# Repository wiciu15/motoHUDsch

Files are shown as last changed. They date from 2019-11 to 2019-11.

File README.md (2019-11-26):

# motoHUDsch
KiCad Schematic and PCB for STM32F103-based motorcycle digital instrument cluster with 2.8in ILI9341 LCD and X27.168 stepper motor for dial gauge indicator.

<b>Firmware - https://github.com/wiciu15/motoHUDini</b>

<b>Enclosure - https://github.com/wiciu15/motoHUDencl </b>

<b>Demo video - https://youtu.be/awKXkiaZZUE</b>

3d back

3d front

final render

Rev1 has problems with thermals on 5V regulator, ADC accuracy and other brain farts like bad footprint or silkscreen marking

Rev2 comes with fixes and some new features like button switches. It is not perfect however :/

<b>Rev2 need some mods to work properly:</b>

<b>-U2 needs to be powered from a 5V rail or changed to a rail-to-rail dual opAmp in same package (LM2903 is not rail-to-rail unfortunately)</b>

<b>-C25 and C21 need a parallel resistor to discharge them (100k-200k ohm range)</b>

<b>-startup current is too high and destroys fuses immidately - I switched F1 fuse with a 1206 2,2ohm resistor </b>

If you don't have/like KiCAD there are schematic PDFs and gerber files.

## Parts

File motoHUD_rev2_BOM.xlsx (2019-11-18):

Item | Qty | Reference(s) | Value | LibPart | Footprint | Link | Cena/szt | Cena
1 | 1 | C11 | 2,2u | Device:C_Small | Capacitor_SMD:C_0805_2012Metric_Pad1.15x1.40mm_HandSolder | ~
2 | 4 | C12, C14, C15, C17 | 10u 16v | Device:C_Small | Capacitor_SMD:C_0805_2012Metric_Pad1.15x1.40mm_HandSolder | ~
3 | 4 | C13, C23, C24, C34 | 0,1u | Device:C_Small | Capacitor_SMD:C_0805_2012Metric_Pad1.15x1.40mm_HandSolder | ~
4 | 1 | C16 | 100u | Device:CP | Capacitor_THT:CP_Radial_D8.0mm_P3.50mm | ~
5 | 4 | C18, C21, C22, C25 | 22u | Device:C_Small | Capacitor_SMD:C_0805_2012Metric_Pad1.15x1.40mm_HandSolder | ~
6 | 4 | C30, C31, C32, C33 | 20p | Device:C_Small | Capacitor_SMD:C_0805_2012Metric_Pad1.15x1.40mm_HandSolder | ~
7 | 4 | D1, D2, D3, D5 | 1N4148W-7-F | Diode:1N4148 | Diode_SMD:D_SOD-123 | https://www.tme.eu/pl/details/1n4148w-7-f/diody-uniwersalne-smd/diodes-incorporated/
8 | 1 | D4 | STPS1L40A | Diode | Diode_SMD:D_SMA_Handsoldering | https://www.tme.eu/pl/details/stps1l40a/diody-schottky-smd/stmicroelectronics/
9 | 4 | D6, D7, D8, D9 | BCKLED | Device:LED | LED_SMD:LED_1206_3216Metric | https://www.tme.eu/pl/details/fyls-1206uwc/diody-led-smd-biale/foryard/
10 | 1 | D10 | LEDSTATUS | Device:LED | LED_SMD:LED_1206_3216Metric_Pad1.42x1.75mm_HandSolder | https://www.tme.eu/pl/details/osr51206c1e/diody-led-smd-kolorowe/optosupply/
11 | 1 | F1 | ESKA FUSE 0805-FF PW 0A5 | Device:Fuse_Small | Capacitor_SMD:C_1206_3216Metric_Pad1.42x1.75mm_HandSolder | https://www.tme.eu/pl/details/bsmd0805-ss0.5/bezpieczniki-smd-0805-superszybkie/eska/fuse-0805-ff-pw-0a5/
12 | 1 | J1 | POWER | Connector:Conn_01x03_Female | Connector_JST:JST_XH_B03B-XH-A_1x03_P2.50mm_Vertical | https://www.tme.eu/pl/details/mx-5267-03a/zlacza-sygnalowe-raster-2-50mm/molex/22-03-5035/
13 | 1 | J2 | THERM1 | Connector:Conn_01x02_Female | Connector_JST:JST_XH_B02B-XH-A_1x02_P2.50mm_Vertical | https://www.tme.eu/pl/details/mx-5267-02a/zlacza-sygnalowe-raster-2-50mm/molex/22-03-5025/
14 | 1 | J3 | THERM2 | Connector:Conn_01x02_Female | Connector_JST:JST_XH_B02B-XH-A_1x02_P2.50mm_Vertical | https://www.tme.eu/pl/details/mx-5267-02a/zlacza-sygnalowe-raster-2-50mm/molex/22-03-5025/
15 | 1 | J4 | HALL | Connector:Conn_01x03_Female | Connector_JST:JST_XH_B03B-XH-A_1x03_P2.50mm_Vertical | https://www.tme.eu/pl/details/mx-5267-03a/zlacza-sygnalowe-raster-2-50mm/molex/22-03-5035/
16 | 1 | J5 | SIG_RPM | Connector:Conn_01x02_Female | Connector_JST:JST_XH_B02B-XH-A_1x02_P2.50mm_Vertical | https://www.tme.eu/pl/details/mx-5267-02a/zlacza-sygnalowe-raster-2-50mm/molex/22-03-5025/
17 | 1 | J6 | SIGNAL | Connector:Conn_01x03_Female | Connector_JST:JST_XH_B03B-XH-A_1x03_P2.50mm_Vertical | https://www.tme.eu/pl/details/mx-5267-03a/zlacza-sygnalowe-raster-2-50mm/molex/22-03-5035/
18 | 1 | J7 | USB_B_Mini | Connector:USB_B_Mini | Connector_USB:USB_Mini-B_Lumberg_2486_01_Horizontal | https://www.tme.eu/pl/details/musb-b5-s-ra-smt/zlacza-usb-i-ieee1394/adam-tech/musb-b5-s-ra-tsmt-cs1/
19 | 1 | J8 | ICSP | Connector:Conn_01x03_Male | Connector_PinHeader_2.54mm:PinHeader_1x03_P2.54mm_Vertical | goldpin
20 | 1 | J9 | LCD Connector | Connector:Conn_01x18_Female | motoHUD:ILI9341 FFC | https://pl.aliexpress.com/item/32861524235.html?spm=a2g0s.9042311.0.0.60ae5c0fPdHgZW
21 | 1 | L1 | DLG-0403-220 | Device:L | Inductor_SMD:L_2816_7142Metric_Pad3.20x4.45mm_HandSolder | https://www.tme.eu/pl/details/dlg-0403-220/dlawiki-smd-mocy/ferrocore/
22 | 1 | M1 | X27 168 | Motor:Stepper_Motor_bipolar | motoHUD:X27-168 | http://www.infineon.com/dgdl/Application-Note-TLE8110EE_driving_UniPolarStepperMotor_V1.1.pdf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
23 | 2 | Q1, Q2 | 2N7002KQ-13 | Device:Q_NMOS_DGS | motoHUD:SOT-23 | https://www.tme.eu/pl/details/2n7002kq-13/tranzystory-z-kanalem-n-smd/diodes-incorporated/
24 | 6 | R11, R27, R28, R31, R54, R61 | 100k | Device:R | Resistor_SMD:R_0805_2012Metric_Pad1.15x1.40mm_HandSolder | ~
25 | 1 | R12 | 22k | Device:R | Resistor_SMD:R_0805_2012Metric_Pad1.15x1.40mm_HandSolder | ~
26 | 1 | R13 | 51,1k | Device:R | Resistor_SMD:R_0805_2012Metric_Pad1.15x1.40mm_HandSolder | ~
27 | 3 | R14, R73, R74 | 1,5k | Device:R | Resistor_SMD:R_0805_2012Metric_Pad1.15x1.40mm_HandSolder | ~
28 | 10 | R15, R21, R29, R41, R43, R45, R51, R52, R55, R211 | 10k | Device:R | Resistor_SMD:R_0805_2012Metric_Pad1.15x1.40mm_HandSolder | ~
29 | 4 | R16, R17, R32, R62 | 0R | Device:R | Resistor_SMD:R_0805_2012Metric_Pad1.15x1.40mm_HandSolder | ~
30 | 2 | R22, R23 | 7,6k | Device:R | Resistor_SMD:R_0805_2012Metric_Pad1.15x1.40mm_HandSolder | ~
31 | 2 | R24, R25 | 5,1k | Device:R | Resistor_SMD:R_0805_2012Metric_Pad1.15x1.40mm_HandSolder | ~
32 | 1 | R26 | 2,2k | Device:R | Resistor_SMD:R_0805_2012Metric_Pad1.15x1.40mm_HandSolder | ~
33 | 4 | R33, R34, R35, R36 | 100R | Device:R | Resistor_SMD:R_0805_2012Metric_Pad1.15x1.40mm_HandSolder | ~
34 | 3 | R42, R44, R46 | 3k3 | Device:R | Resistor_SMD:R_0805_2012Metric_Pad1.15x1.40mm_HandSolder | ~
35 | 2 | R53, R210 | 1M | Device:R | Resistor_SMD:R_0805_2012Metric_Pad1.15x1.40mm_HandSolder | ~
36 | 4 | R63, R64, R65, R66 | 39R | Device:R | Resistor_SMD:R_0805_2012Metric_Pad1.15x1.40mm_HandSolder | ~
37 | 2 | R71, R72 | 22R | Device:R | Resistor_SMD:R_0805_2012Metric_Pad1.15x1.40mm_HandSolder | ~
38 | 1 | SW1 | TACTM-613N-F | Switch:SW_Push | Button_Switch_SMD:SW_SPST_EVQQ2 | https://www.tme.eu/pl/details/tactm-613n-f/mikroprzelaczniki-tact/ninigi/
39 | 1 | U1 | STM32F103C8Tx | MCU_ST_STM32F1:STM32F103C8Tx | Package_QFP:LQFP-48_7x7mm_P0.5mm | https://www.tme.eu/pl/details/stm32f103c8t6/mikrokontrolery-st/stmicroelectronics/
40 | 2 | U2, U3 | LM2904DT | Amplifier_Operational:LM2904 | Package_SO:SO-8_5.3x6.2mm_P1.27mm | https://www.tme.eu/pl/details/lm2904dt/wzmacniacze-operacyjne-smd/stmicroelectronics/
41 | 1 | U4 | AZ1117-3.3 | Regulator_Linear:AZ1117-3.3 | Package_TO_SOT_SMD:SOT-223 | https://www.tme.eu/pl/details/az1117ch-3.3trg1/stabilizatory-napiecia-nieregulowane-ldo/diodes-incorporated/
42 | 1 | U5 | MCP16301 | Regulator_Switching:MCP16301 | Package_TO_SOT_SMD:SOT-23-6 | https://www.tme.eu/pl/details/mcp16301t-i_chy/regulatory-napiecia-uklady-dc-dc/microchip-technology/
43 | 1 | U6 | M95320-WMN6P | Memory_EEPROM:M95256-WMN6P | Package_SO:SOIC-8_3.9x4.9mm_P1.27mm | https://www.tme.eu/pl/details/m95320-wmn6tp/pamieci-eeprom-szeregowe/stmicroelectronics/
44 | 1 | Y1 | HC49USM-FF3F18-8M | Device:Crystal | Crystal:Crystal_SMD_HC49-SD_HandSoldering | https://www.tme.eu/pl/details/hc49usm-ff3f8.00/rezonatory-kwarcowe-smd/ilsi/hc49usm-ff3f18-8-0000/
45 | 1 | Y2 | LFXTAL009678 | Device:Crystal | Crystal:Crystal_SMD_3215-2Pin_3.2x1.5mm | https://www.tme.eu/pl/details/32.768k-cfpx217/rezonatory-kwarcowe-smd/iqd-frequency-products/lfxtal009678/

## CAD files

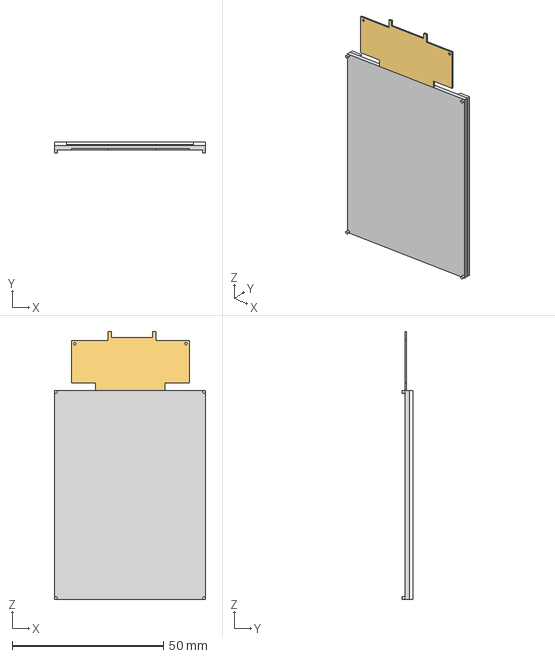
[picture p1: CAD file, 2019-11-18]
28inLCDILI9341.step
50.0 x 3.60 x 88.7 mm

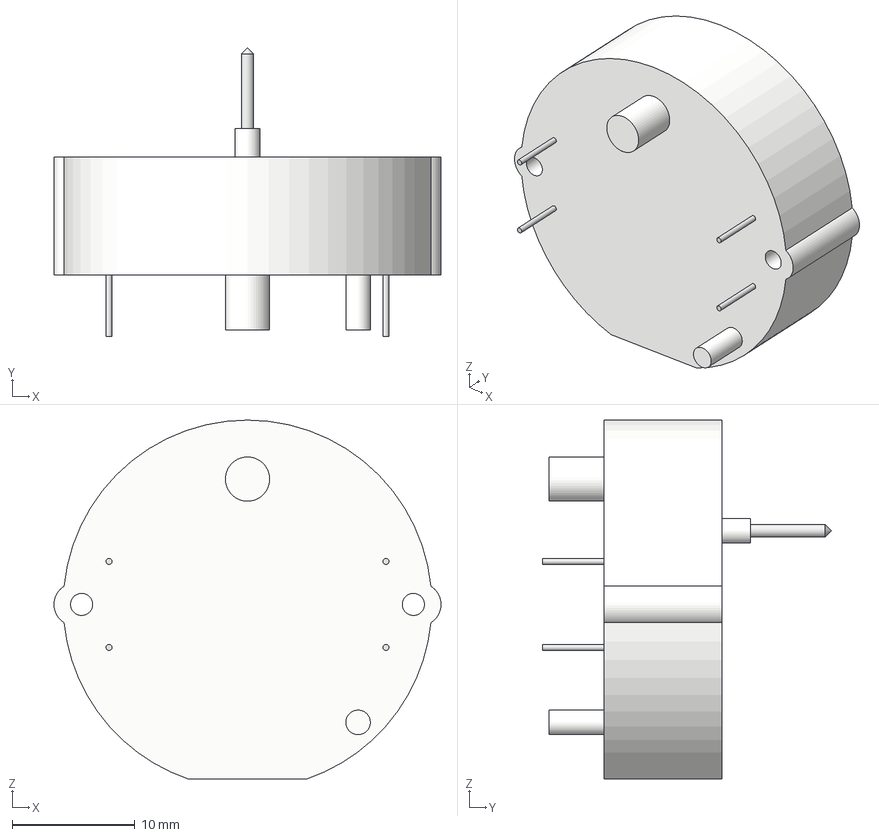
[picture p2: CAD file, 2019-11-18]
x27168.step
31.5 x 23.5 x 29.2 mm

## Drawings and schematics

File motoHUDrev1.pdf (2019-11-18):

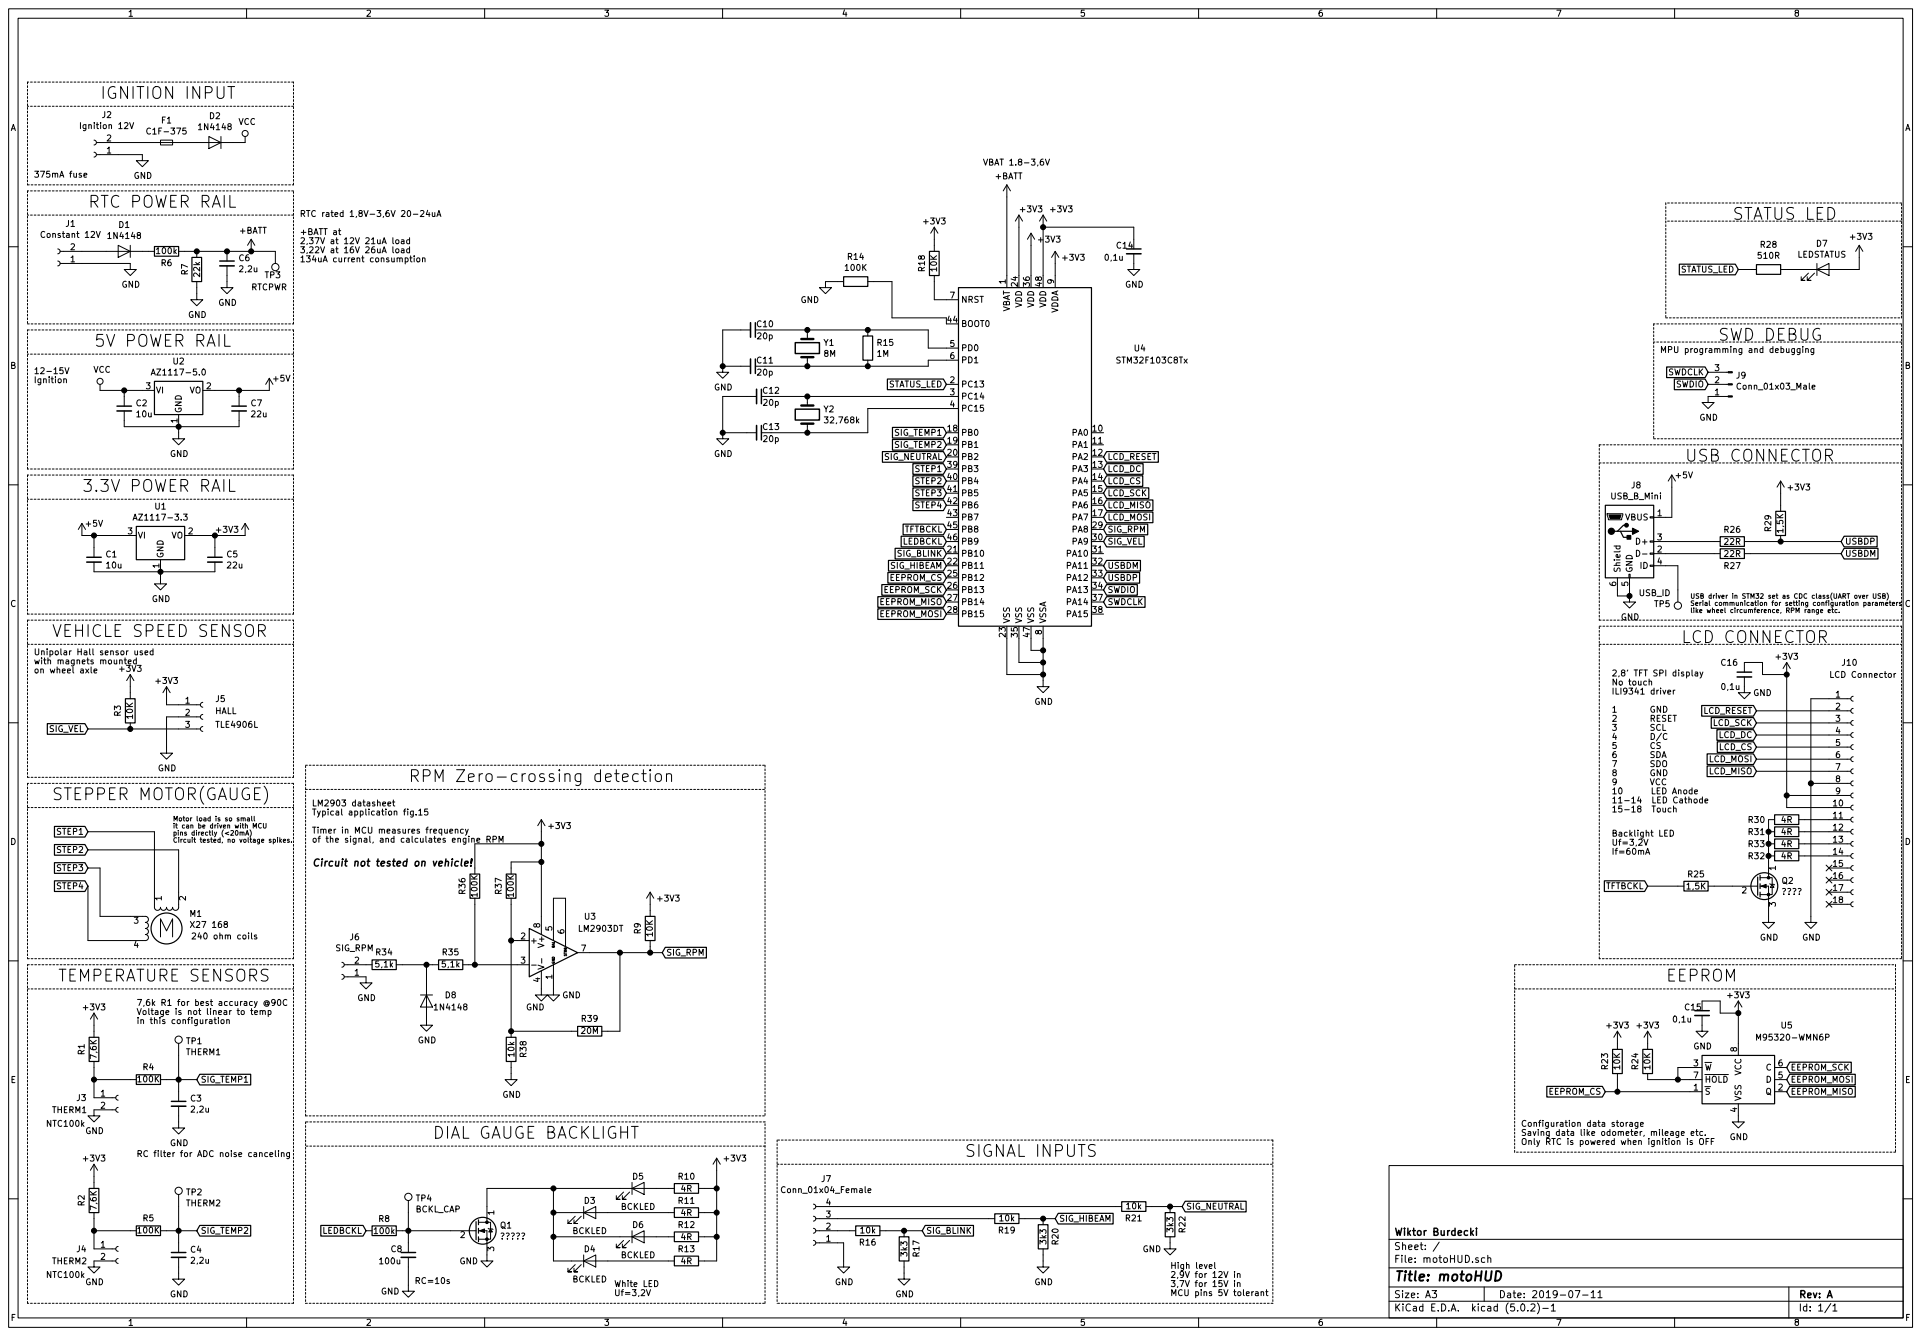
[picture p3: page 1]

375mA fuse Unipolar Hall sensor used
1N4148 RTC POWER RAIL

RTC rated 1,8V-3,6V 20-24uA
+BATT at 2,37V at 12V 21uA load

STATUS LED

1 VDD 24 VDD 36 VDD 48 VDDA

9 VSS 23 VSS 35 VSS 47 VSSA

like wheel circumference, RPM range etc. MPU programming and debugging

USB driver in STM32 set as CDC class(UART over USB) Serial communication for setting configuration parameters

VEHICLE SPEED SENSOR

LCD CONNECTOR

LCD_MOSI 2,8' TFT SPI display No touch

240 ohm coils STEPPER MOTOR(GAUGE)

LM2903 datasheet Typical application fig.15

it can be driven with MCU

Timer in MCU measures frequency
of the signal, and calculates engine RPM

TEMPERATURE SENSORS

Voltage is not linear to temp
in this configuration

Configuration data storage Saving data like odometer, mileage etc. Only RTC is powered when ignition is OFF

RC filter for ADC noise canceling

SIG_NEUTRAL High level 2,9V for 12V in

File: motoHUD.sch Sheet: / Wiktor Burdecki

3,7V for 15V in MCU pins 5V tolerant

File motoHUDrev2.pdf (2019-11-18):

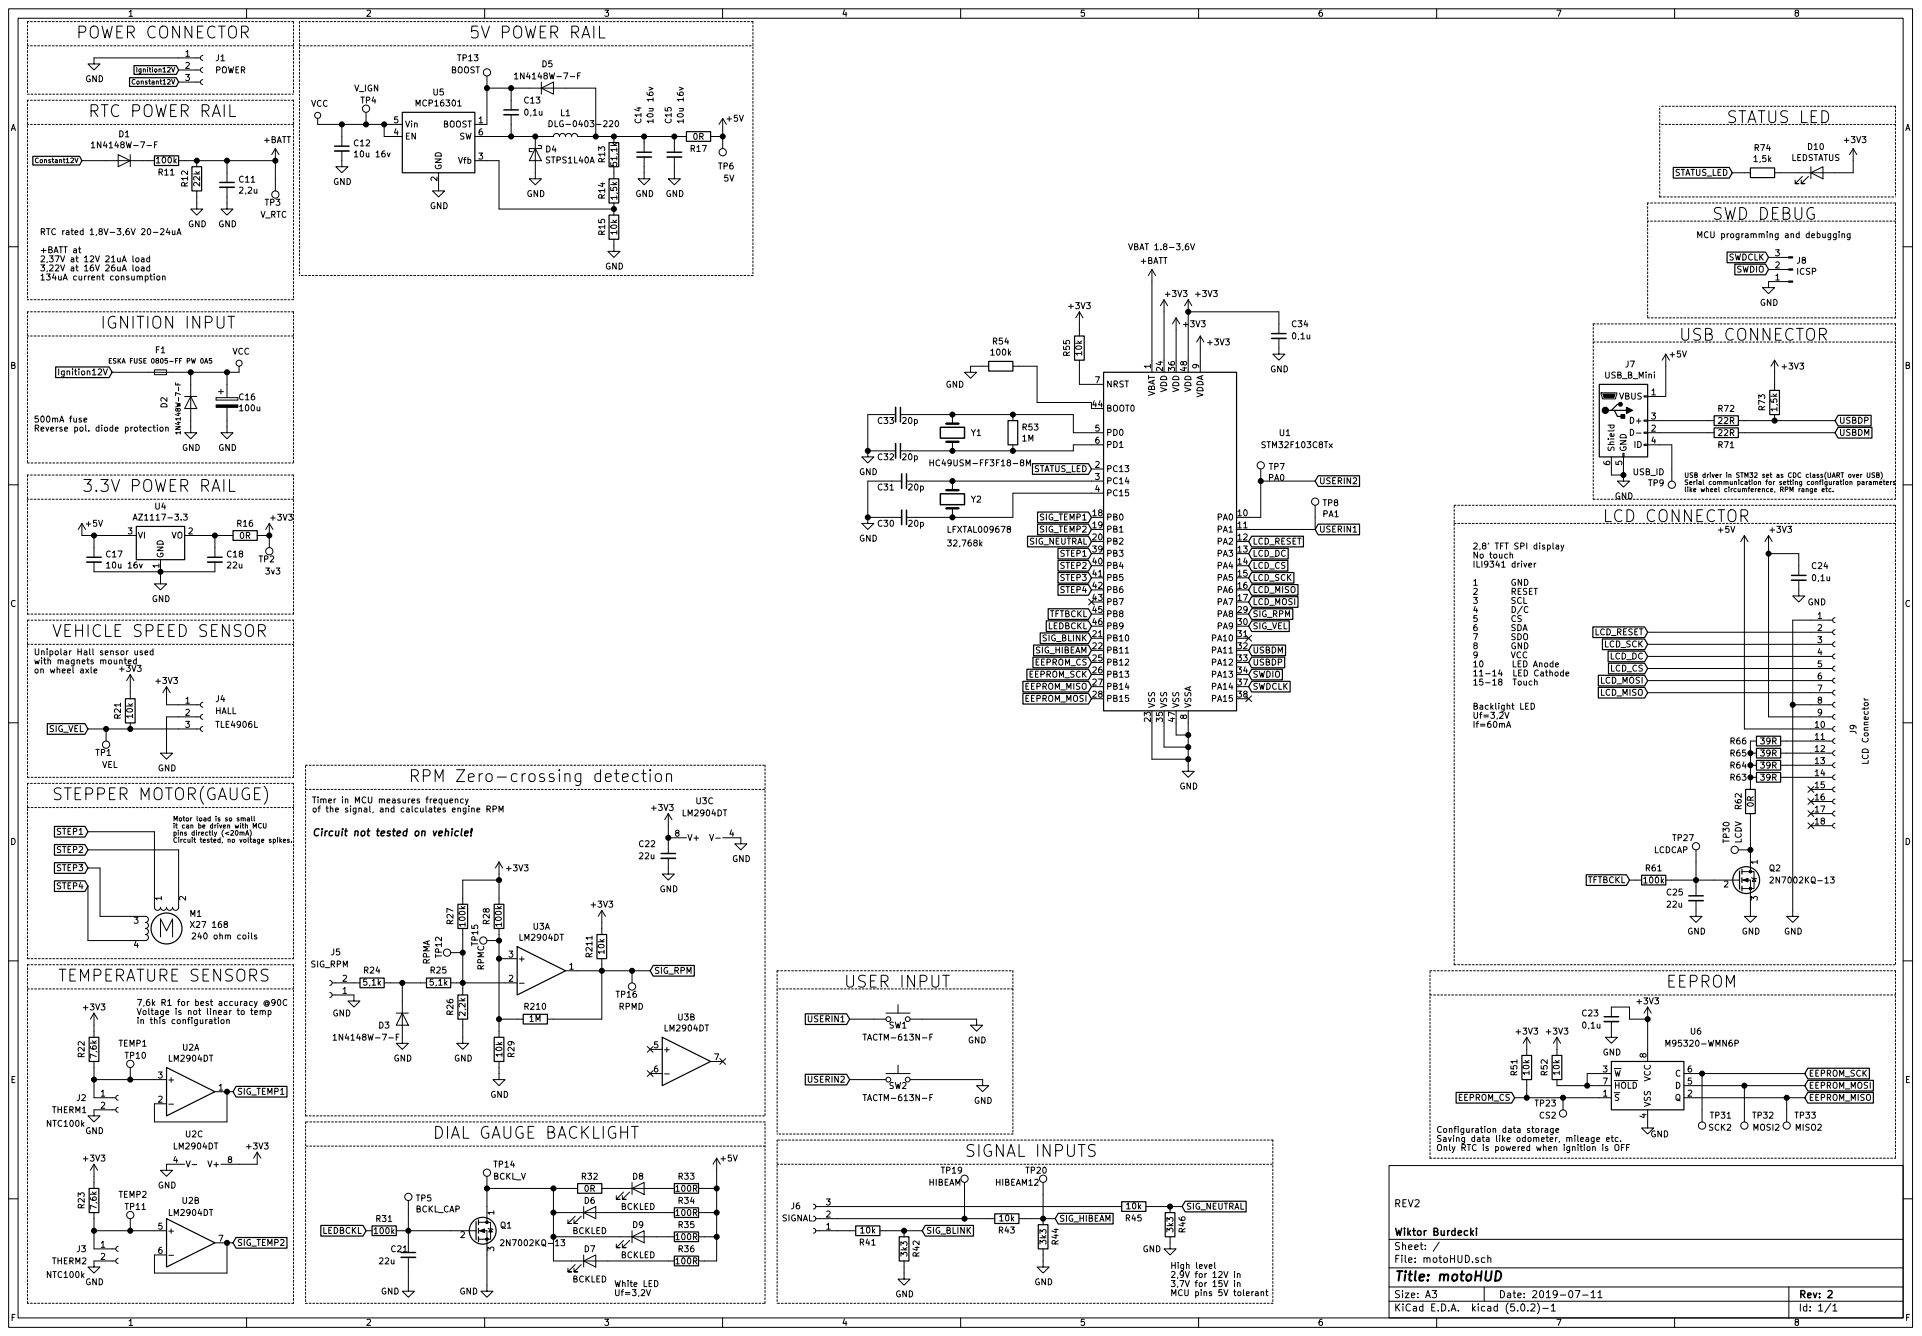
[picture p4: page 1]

2 Vfb 3 EN 4 Vin 5 SW 6 U5 MCP16301 GND

RTC rated 1,8V-3,6V 20-24uA
+BATT at 2,37V at 12V 21uA load
3,22V at 16V 26uA load

like wheel circumference, RPM range etc. MCU programming and debugging

ESKA FUSE 0805-FF PW 0A5

1 VDD 24 VDD 36 VDD 48 VDDA

9 VSS 23 VSS 35 VSS 47 VSSA

500mA fuse Reverse pol. diode protection

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

LCD_MOSI 2,8' TFT SPI display No touch

VEHICLE SPEED SENSOR | 3v3 TP1VEL

Unipolar Hall sensor used with magnets mounted

240 ohm coils STEPPER MOTOR(GAUGE)

Timer in MCU measures frequency

it can be driven with MCU

7,6k R1 for best accuracy @90C
Voltage is not linear to temp

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

SIG_NEUTRAL High level 2,9V for 12V in

File: motoHUD.sch Sheet: / Wiktor Burdecki REV2

3,7V for 15V in MCU pins 5V tolerant

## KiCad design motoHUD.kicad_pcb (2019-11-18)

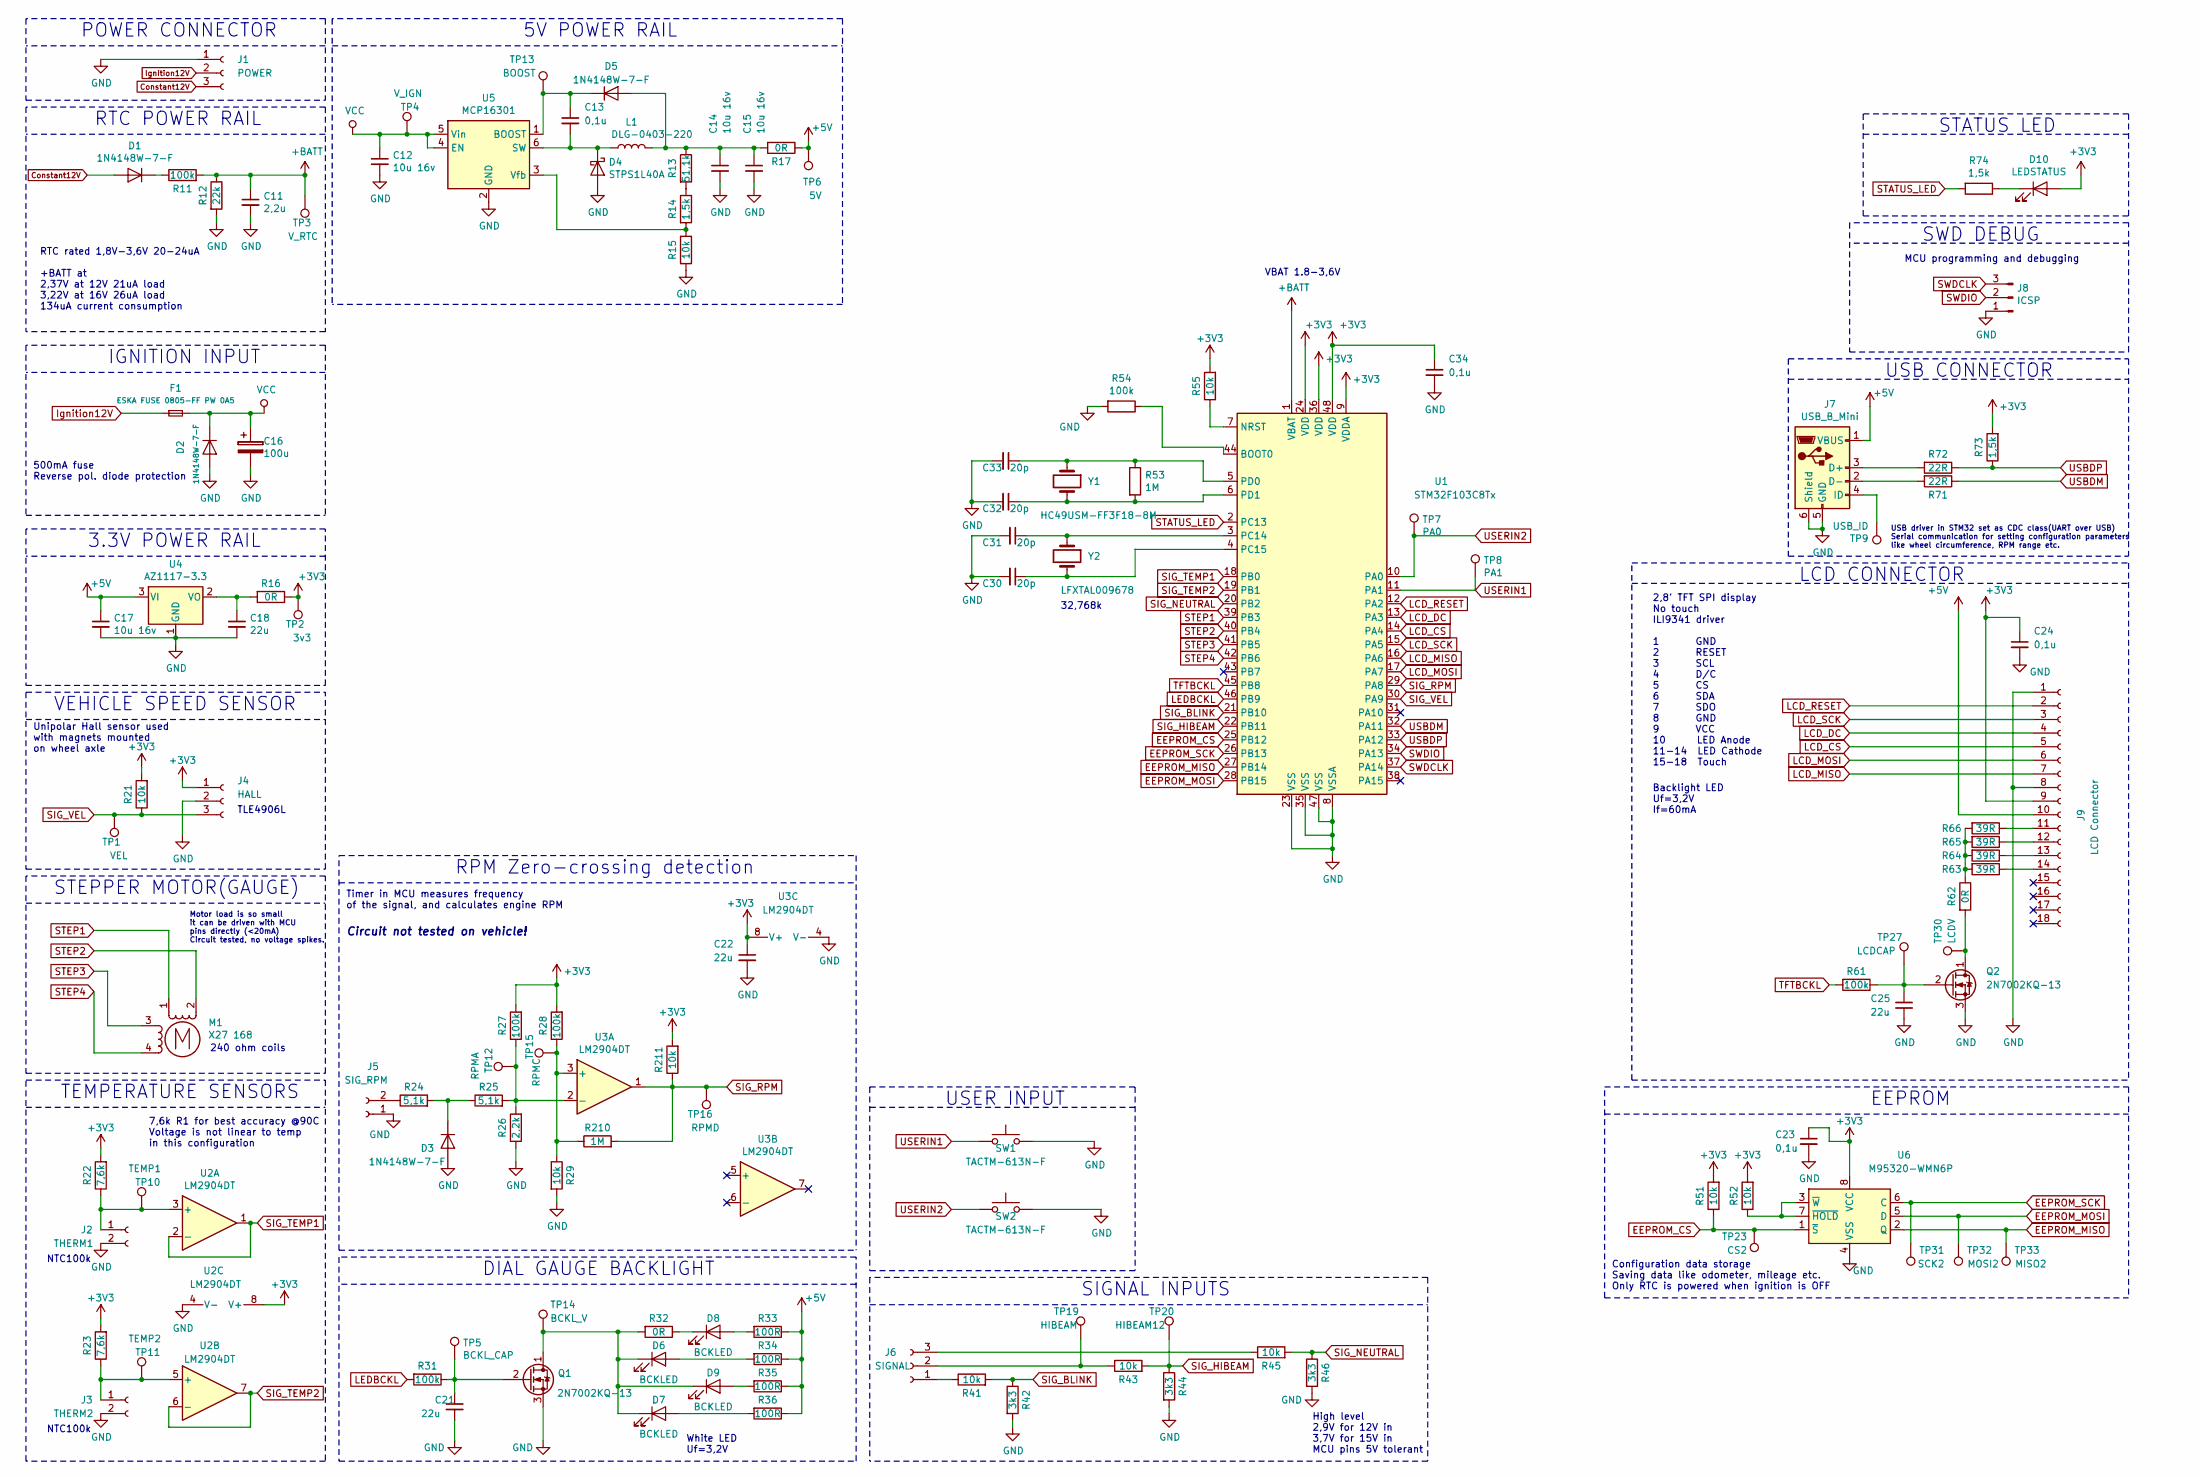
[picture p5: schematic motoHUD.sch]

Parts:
C11: 2,2u; C_0805_2012Metric_Pad1.15x1.40mm_HandSolder
C12, C14, C15, C17: 10u 16v; C_0805_2012Metric_Pad1.15x1.40mm_HandSolder
C13, C23, C24, C34: 0,1u; C_0805_2012Metric_Pad1.15x1.40mm_HandSolder
C16: 100u; CP_Radial_D8.0mm_P3.50mm
C18, C21, C22, C25: 22u; C_0805_2012Metric_Pad1.15x1.40mm_HandSolder
C30, C31, C32, C33: 20p; C_0805_2012Metric_Pad1.15x1.40mm_HandSolder
D1, D2, D3, D5: 1N4148W-7-F; D_SOD-123
D4: STPS1L40A; D_SMA_Handsoldering
D6, D7, D8, D9: BCKLED; LED_1206_3216Metric
D10: LEDSTATUS; LED_1206_3216Metric_Pad1.42x1.75mm_HandSolder
F1: ESKA FUSE 0805-FF PW 0A5; C_1206_3216Metric_Pad1.42x1.75mm_HandSolder
J1: POWER; JST_XH_B03B-XH-A_1x03_P2.50mm_Vertical
J2: THERM1; JST_XH_B02B-XH-A_1x02_P2.50mm_Vertical
J3: THERM2; JST_XH_B02B-XH-A_1x02_P2.50mm_Vertical
J4: HALL; JST_XH_B03B-XH-A_1x03_P2.50mm_Vertical
J5: SIG_RPM; JST_XH_B02B-XH-A_1x02_P2.50mm_Vertical
J6: SIGNAL; JST_XH_B03B-XH-A_1x03_P2.50mm_Vertical
J7: USB_B_Mini; USB_Mini-B_Lumberg_2486_01_Horizontal
J8: ICSP; PinHeader_1x03_P2.54mm_Vertical
J9: LCD Connector; ILI9341FFC
L1: DLG-0403-220
M1: X27 168; X27-168
Q1, Q2: 2N7002KQ-13; SOT-23
R11, R27, R28, R31, R54, R61: 100k; R_0805_2012Metric_Pad1.15x1.40mm_HandSolder
R12: 22k; R_0805_2012Metric_Pad1.15x1.40mm_HandSolder
R13: 51,1k; R_0805_2012Metric_Pad1.15x1.40mm_HandSolder
R14, R73, R74: 1,5k; R_0805_2012Metric_Pad1.15x1.40mm_HandSolder
R15, R21, R29, R41, R43, R45, R51, R52, R55, R211: 10k; R_0805_2012Metric_Pad1.15x1.40mm_HandSolder
R16, R17, R32, R62: 0R; R_0805_2012Metric_Pad1.15x1.40mm_HandSolder
R22, R23: 7,6k; R_0805_2012Metric_Pad1.15x1.40mm_HandSolder
R24, R25: 5,1k; R_0805_2012Metric_Pad1.15x1.40mm_HandSolder
R26: 2,2k; R_0805_2012Metric_Pad1.15x1.40mm_HandSolder
R33, R34, R35, R36: 100R; R_0805_2012Metric_Pad1.15x1.40mm_HandSolder
R42, R44, R46: 3k3; R_0805_2012Metric_Pad1.15x1.40mm_HandSolder
R53, R210: 1M; R_0805_2012Metric_Pad1.15x1.40mm_HandSolder
R63, R64, R65, R66: 39R; R_0805_2012Metric_Pad1.15x1.40mm_HandSolder
R71, R72: 22R; R_0805_2012Metric_Pad1.15x1.40mm_HandSolder
SW1, SW2: TACTM-613N-F
TP1: VEL; TestPoint_THTPad_D2.0mm_Drill1.0mm
TP2: 3v3; TestPoint_THTPad_D2.0mm_Drill1.0mm
TP3: V_RTC; TestPoint_THTPad_D2.0mm_Drill1.0mm
TP4: V_IGN; TestPoint_THTPad_D2.0mm_Drill1.0mm
TP5: BCKL_CAP; TestPoint_THTPad_D2.0mm_Drill1.0mm
TP6: 5V; TestPoint_THTPad_D2.0mm_Drill1.0mm
TP7: PA0; TestPoint_THTPad_D2.0mm_Drill1.0mm
TP8: PA1; TestPoint_THTPad_D2.0mm_Drill1.0mm
TP9: USB_ID; TestPoint_THTPad_D2.0mm_Drill1.0mm
TP10: TEMP1; TestPoint_THTPad_D2.0mm_Drill1.0mm
TP11: TEMP2; TestPoint_THTPad_D2.0mm_Drill1.0mm
TP12: RPMA; TestPoint_THTPad_D2.0mm_Drill1.0mm
TP13: BOOST; TestPoint_THTPad_D2.0mm_Drill1.0mm
TP14: BCKL_V; TestPoint_THTPad_D2.0mm_Drill1.0mm
TP15: RPMC; TestPoint_THTPad_D2.0mm_Drill1.0mm
TP16: RPMD; TestPoint_THTPad_D2.0mm_Drill1.0mm
TP19: HIBEAM; TestPoint_THTPad_D2.0mm_Drill1.0mm
TP20: HIBEAM12; TestPoint_THTPad_D2.0mm_Drill1.0mm
TP23: CS2; TestPoint_THTPad_D2.0mm_Drill1.0mm
TP27: LCDCAP; TestPoint_THTPad_D2.0mm_Drill1.0mm
TP30: LCDV; TestPoint_THTPad_D2.0mm_Drill1.0mm
TP31: SCK2; TestPoint_THTPad_D2.0mm_Drill1.0mm
TP32: MOSI2; TestPoint_THTPad_D2.0mm_Drill1.0mm
TP33: MISO2; TestPoint_THTPad_D2.0mm_Drill1.0mm
U1: STM32F103C8Tx; LQFP-48_7x7mm_P0.5mm
U2, U3: LM2904DT; SO-8_5.3x6.2mm_P1.27mm
U4: AZ1117-3.3; SOT-223
U5: MCP16301; SOT-23-6
U6: M95320-WMN6P; SOIC-8_3.9x4.9mm_P1.27mm
Y1: HC49USM-FF3F18-8M; Crystal_SMD_HC49-SD_HandSoldering
Y2: LFXTAL009678; Crystal_SMD_3215-2Pin_3.2x1.5mm

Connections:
+3V3: C22.1, C23.1, C24.1, C34.1, D10.2 (A), J4.1, J9.9, R16.1, R21.2, R22.2, R23.2, R27.2, R28.2, R51.2, R52.2, R55.2, R73.2, R211.2, TP2.1, U1.9 (VDDA), U1.24 (VDD), U1.36 (VDD), U1.48 (VDD), U2.8 (V+), U3.8 (V+), U6.8 (VCC)
+5V: C17.1, J7.1 (VBUS), J9.10, R17.1, R33.1, R34.1, R35.1, R36.1, TP6.1, U4.3 (VI)
+BATT: C11.1, R11.2, R12.1, TP3.1, U1.1 (VBAT)
Constant12V: D1.2 (A), J1.3
EEPROM_CS: R51.1, TP23.1, U1.25 (PB12), U6.1 (~S)
EEPROM_MISO: TP33.1, U1.27 (PB14), U6.2 (Q)
EEPROM_MOSI: TP32.1, U1.28 (PB15), U6.5 (D)
EEPROM_SCK: TP31.1, U1.26 (PB13), U6.6 (C)
GND: C11.2, C12.2, C14.2, C15.2, C16.2, C17.2, C18.2, C21.2, C22.2, C23.2, C24.2, C25.2, C30.2, C31.2, C32.2, C33.2, C34.2, D2.2 (A), D3.2 (A), D4.2 (A), J1.1, J2.2, J3.2, J4.2, J5.1, J7.5 (GND), J7.6 (Shield), J8.1, J9.1, J9.8, Q1.3 (S), Q2.3 (S), R12.2, R15.2, R26.1, R29.2, R42.2, R44.2, R46.2, R54.2, SW1.2, SW2.2, U1.8 (VSSA), U1.23 (VSS), U1.35 (VSS), U1.47 (VSS), U2.4 (V-), U3.4 (V-), U4.1 (GND), U5.2 (GND), U6.4 (VSS)
Ignition12V: F1.1, J1.2
LCD_CS: J9.5, U1.14 (PA4)
LCD_DC: J9.4, U1.13 (PA3)
LCD_MISO: J9.7, U1.16 (PA6)
LCD_MOSI: J9.6, U1.17 (PA7)
LCD_RESET: J9.2, U1.12 (PA2)
LCD_SCK: J9.3, U1.15 (PA5)
LEDBCKL: R31.2, U1.46 (PB9)
unnamed: C13.1, D5.1 (K), TP13.1, U5.1 (BOOST)
unnamed: C13.2, D4.1 (K), L1.1, U5.6 (SW)
unnamed: C14.1, C15.1, D5.2 (A), L1.2, R13.1, R17.2
unnamed: C18.1, R16.2, U4.2 (VO)
unnamed: C21.1, Q1.2 (G), R31.1, TP5.1
unnamed: C25.1, Q2.2 (G), R61.1, TP27.1
unnamed: C30.1, U1.4 (PC15), Y2.2
unnamed: C31.1, U1.3 (PC14), Y2.1
unnamed: C32.1, R53.2, U1.6 (PD1), Y1.2
unnamed: C33.1, R53.1, U1.5 (PD0), Y1.1
unnamed: D1.1 (K), R11.1
unnamed: D3.1 (K), R24.2, R25.1
unnamed: D6.1 (K), D7.1 (K), D9.1 (K), Q1.1 (D), R32.2, TP14.1
unnamed: D6.2 (A), R34.2
unnamed: D7.2 (A), R36.2
unnamed: D8.1 (K), R32.1
unnamed: D8.2 (A), R33.2
unnamed: D9.2 (A), R35.2
unnamed: D10.1 (K), R74.1
unnamed: J2.1, R22.1, TP10.1, U2.3 (+)
unnamed: J3.1, R23.1, TP11.1, U2.5 (+)
unnamed: J5.2, R24.1
unnamed: J6.1, R41.1
unnamed: J6.2, R43.1, TP19.1
unnamed: J6.3, R45.1
unnamed: J7.2 (D-), R71.2
unnamed: J7.3 (D+), R72.2
unnamed: J7.4 (ID), TP9.1
unnamed: J9.11, R66.1
unnamed: J9.12, R65.1
unnamed: J9.13, R64.1
unnamed: J9.14, R63.1
unnamed: Q2.1 (D), R62.2, TP30.1
unnamed: R13.2, R14.1
unnamed: R14.2, R15.1, U5.3 (Vfb)
unnamed: R25.2, R26.2, R27.1, TP12.1, U3.2 (-)
unnamed: R52.1, U6.3 (~W), U6.7 (~HOLD)
unnamed: R54.1, U1.44 (BOOT0)
unnamed: R55.1, U1.7 (NRST)
unnamed: R62.1, R63.2, R64.2, R65.2, R66.2
unnamed: R28.1, R29.1, R210.1, TP15.1, U3.3 (+)
SIG_BLINK: R41.2, R42.1, U1.21 (PB10)
SIG_HIBEAM: R43.2, R44.1, TP20.1, U1.22 (PB11)
SIG_NEUTRAL: R45.2, R46.1, U1.20 (PB2)
SIG_RPM: R210.2, R211.1, TP16.1, U1.29 (PA8), U3.1
SIG_TEMP1: U1.18 (PB0), U2.1, U2.2 (-)
SIG_TEMP2: U1.19 (PB1), U2.6 (-), U2.7
SIG_VEL: J4.3, R21.1, TP1.1, U1.30 (PA9)
STATUS_LED: R74.2, U1.2 (PC13)
STEP1: M1.1, U1.39 (PB3)
STEP2: M1.2 (-), U1.40 (PB4)
STEP3: M1.3, U1.41 (PB5)
STEP4: M1.4, U1.42 (PB6)
SWDCLK: J8.3, U1.37 (PA14)
SWDIO: J8.2, U1.34 (PA13)
TFTBCKL: R61.2, U1.45 (PB8)
USBDM: R71.1, U1.32 (PA11)
USBDP: R72.1, R73.1, U1.33 (PA12)
USERIN1: SW1.1, TP8.1, U1.11 (PA1)
USERIN2: SW2.1, TP7.1, U1.10 (PA0)
VCC: C12.1, C16.1, D2.1 (K), F1.2, TP4.1, U5.4 (EN), U5.5 (Vin)

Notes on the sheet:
2,8' TFT SPI display No touch ILI9341 driver 1 GND 2 RESET 3 SCL 4 D/C 5 CS 6 SDA 7 SDO 8 GND 9 VCC 10 LED Anode 11-14 LED Cathode 15-18 Touch
TLE4906L
NTC100k
EEPROM
LCD CONNECTOR
USB CONNECTOR
SWD DEBUG
STATUS LED
VEHICLE SPEED SENSOR
TEMPERATURE SENSORS
240 ohm coils
STEPPER MOTOR(GAUGE)
DIAL GAUGE BACKLIGHT
White LED Uf=3,2V
Backlight LED Uf=3,2V If=60mA
High level 2,9V for 12V in 3,7V for 15V in MCU pins 5V tolerant
SIGNAL INPUTS
3.3V POWER RAIL
5V POWER RAIL
VBAT 1.8-3,6V
RTC rated 1,8V-3,6V 20-24uA +BATT at 2,37V at 12V 21uA load 3,22V at 16V 26uA load 134uA current consumption
RTC POWER RAIL
IGNITION INPUT
RPM Zero-crossing detection
Configuration data storage Saving data like odometer, mileage etc. Only RTC is powered when ignition is OFF
USB driver in STM32 set as CDC class(UART over USB) Serial communication for setting configuration parameters like wheel circumference, RPM range etc.
MCU programming and debugging
500mA fuse Reverse pol. diode protection
Unipolar Hall sensor used with magnets mounted on wheel axle
Motor load is so small it can be driven with MCU pins directly (<20mA) Circuit tested, no voltage spikes.
Circuit not tested on vehicle!
POWER CONNECTOR
Timer in MCU measures frequency of the signal, and calculates engine RPM
32,768k
7,6k R1 for best accuracy @90C Voltage is not linear to temp in this configuration
USER INPUT

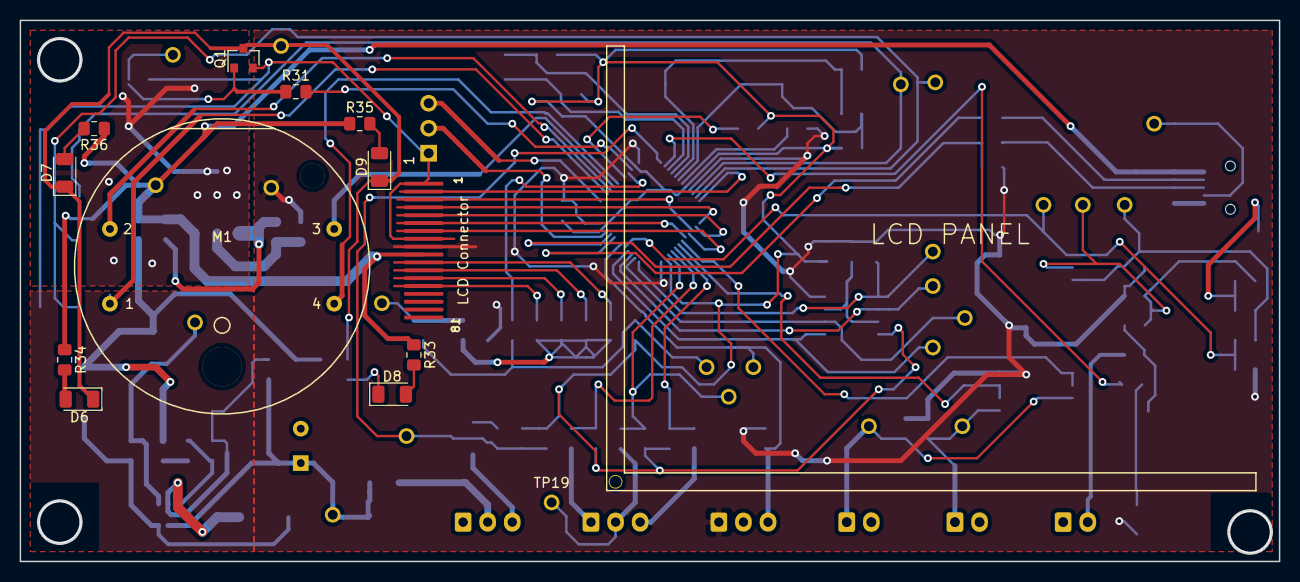
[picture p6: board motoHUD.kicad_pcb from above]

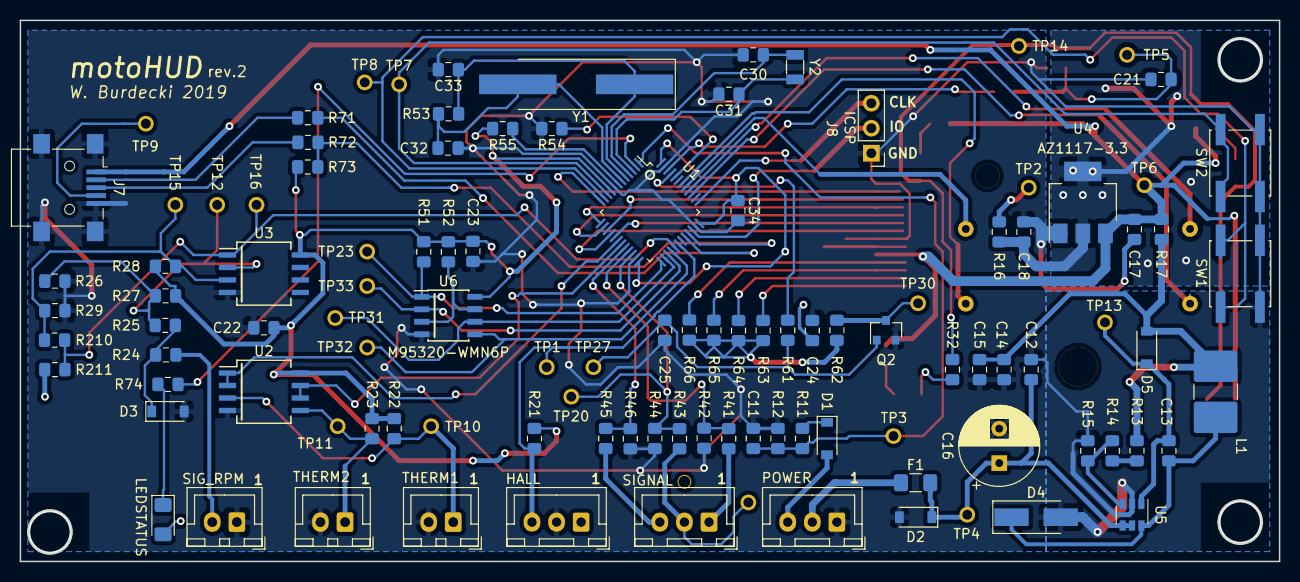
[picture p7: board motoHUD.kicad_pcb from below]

Board: 2 copper layers, 128.0 x 55.0 mm, 121 parts (108 on the bottom side), 78 nets.

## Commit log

2019-07-11 RPM sensing
    [motoHUD.sch]
2019-09-15 Updated PCB layout
    [motoHUD.sch]
2019-10-06 schematic rev2
    2nd revision schematic and updated BOM
    [28inLCDILI9341.step, motoHUD.kicad_pcb, motoHUD.sch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]
2019-10-06 BOM in excel
    [motoHUD_rev2_BOM.xlsx, motoHUDrev2BOM.csv]
2019-10-07 new netlist imported to board design
    [motoHUD.kicad_pcb]
2019-10-07 rev2 layout and footprints updated
    routing TODO
    [motoHUD.kicad_pcb, motoHUD.sch]
2019-10-10 2nd button switch added and routed PCB
    [motoHUD.kicad_pcb, motoHUD.sch]
2019-10-13 pcb design improvements
    [motoHUD.kicad_pcb]
2019-10-21 removed gbr from main dir
    [motoHUD-B.Cu.gbr, motoHUD-B.Mask.gbr, motoHUD-B.SilkS.gbr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]
